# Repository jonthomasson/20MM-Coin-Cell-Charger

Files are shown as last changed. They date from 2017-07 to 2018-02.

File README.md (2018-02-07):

# 20MM-Coin-Cell-Charger
USB based coin cell charger for 2016, 2020, 2025, 2032

This is a very small and affordable lithium coin cell charger. It'll charge several 20mm type coin cell batteries. Total BOM for me was $2 for one. I picked up 3 boards from oshpark for $7.70. The PCB is available to order from the oshpark links below. All files, including BOM to reproduce this project have been included and linked to in my github repository. 

I had the need for an LIR2032 coin cell charger to power a few projects. Unfortunately (or fortunately depending on how you look at it) , the charger I had ordered off Amazon didn't work, so I decided to build my own.

I took the guts of the Solder Sniffer 9000 project, which consisted of an MCP73831 for the charge controller, and modified it a bit to charge an LIR2032.

The main change needed was the value of R3, which is responsible for setting the max charge current. For the LIR2032, the max charge current is 35mA. By using the supplied formula in the MCP73831 datasheet (I = 1000V/R) I was able to find that a 28K resistor would give me the charge current needed. To get a decent connection to the USB socket, I tinned each of the pads a bit.

The value of R3 can be adjusted from anywhere between 28K and 67K. Of course, the higher the resistor, the less charge current and thus the longer the battery will take to charge. 

I wanted the charger to be as compact and simple as possible. For this reason I chose to create the USB plug out of the PCB to save on cost. I also shrank the total footprint of the board to just a little wider than the coin cell holder. 

![enter image description here](https://lh3.googleusercontent.com/uD5Zvyg85dlW-8f5IwnGq1qh3priR2OKTf4Tjj70FocnqzpL80pZEwNxS6ZUOIJZ3bOK8rinoLwqm-kq8-yH0MLIolsSJiKuncZRWuq5fff_9x6JYAw69AOmUJirfUg54P8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)

![enter image description here](https://lh3.googleusercontent.com/PXCVL6h58zrs98nUhsCSNDjTJsKGtNxcaz6ifn4IY02xm1BFlol4Sx9Q6Okw4b5Lm4KdBB9pGmgYVPm0FkVdIyBvV0Q52LWY7phe2oq7p3IzxVEZNmcpIT2coyVlEAW5Eqw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)

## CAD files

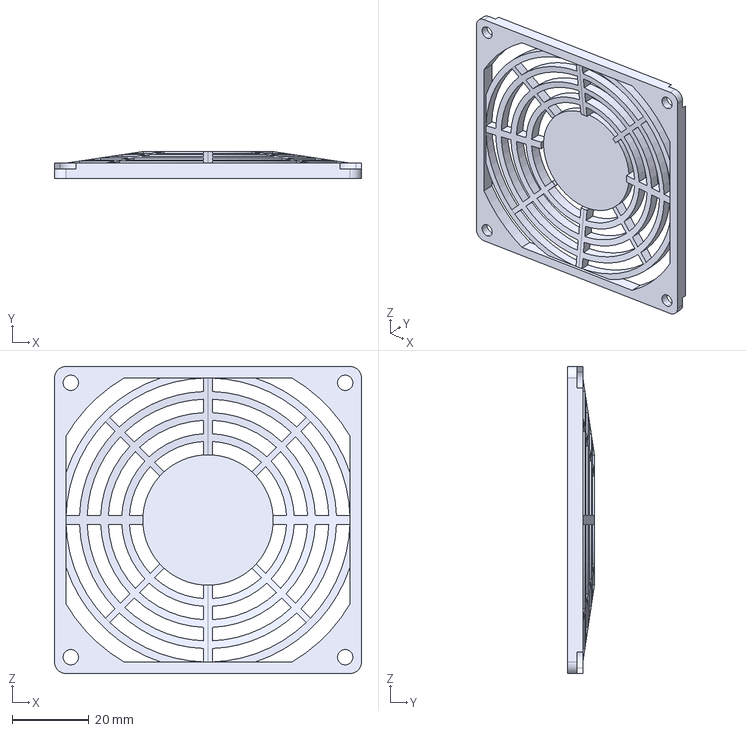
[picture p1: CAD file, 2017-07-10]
rev1.a/3dmodels/80MM_Fan_Filter.step
80.0 x 7.00 x 80.0 mm

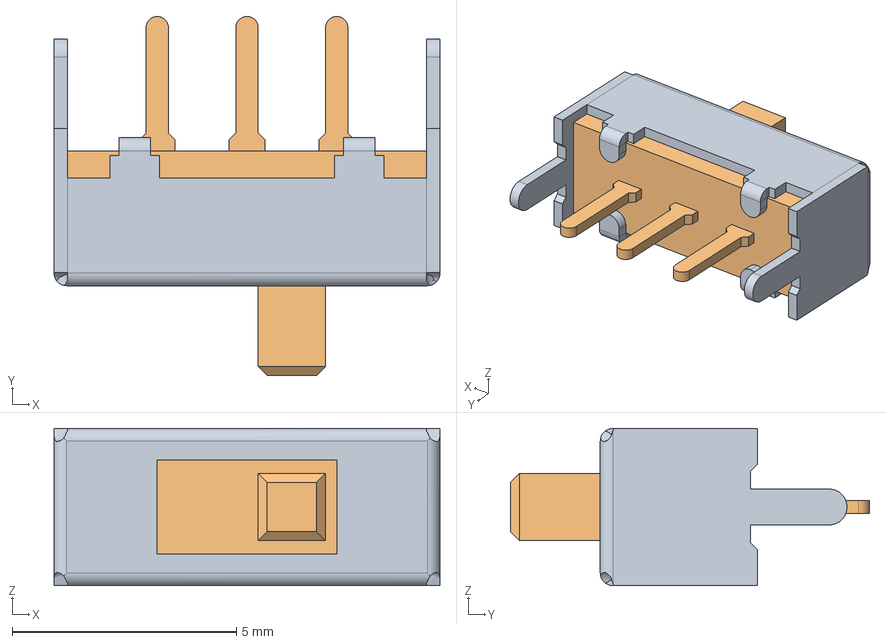
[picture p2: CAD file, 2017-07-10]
rev1.a/3dmodels/Switches_C&K_SS_12D07.step
8.60 x 8.00 x 3.50 mm

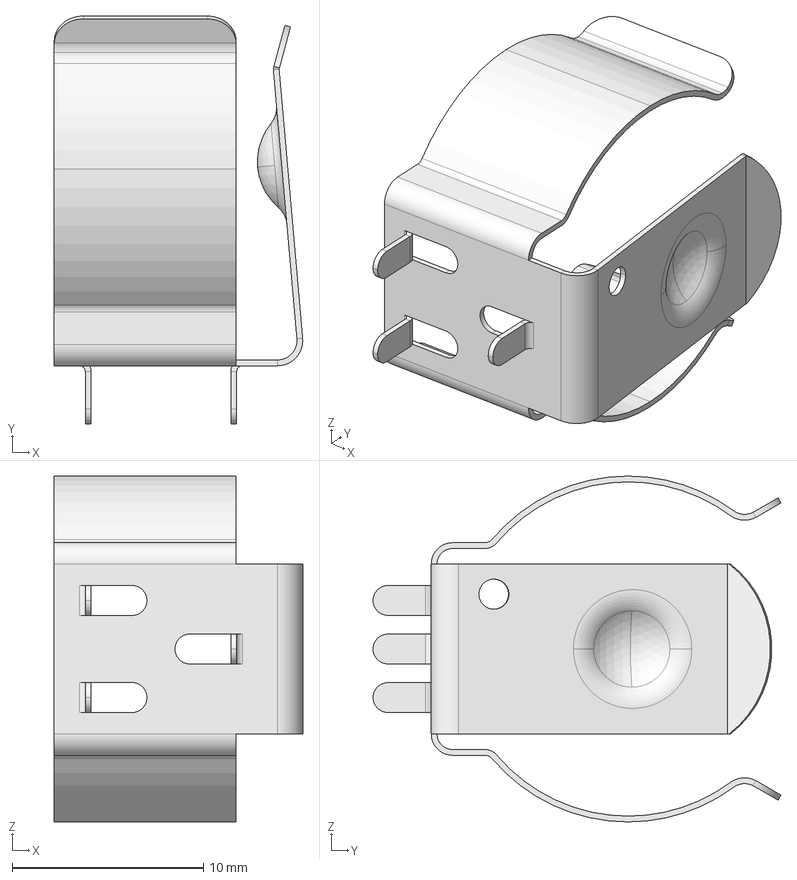
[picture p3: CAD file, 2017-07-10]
rev1.a/3dmodels/Batteries_Keystone_54.step
13.0 x 21.4 x 18.1 mm

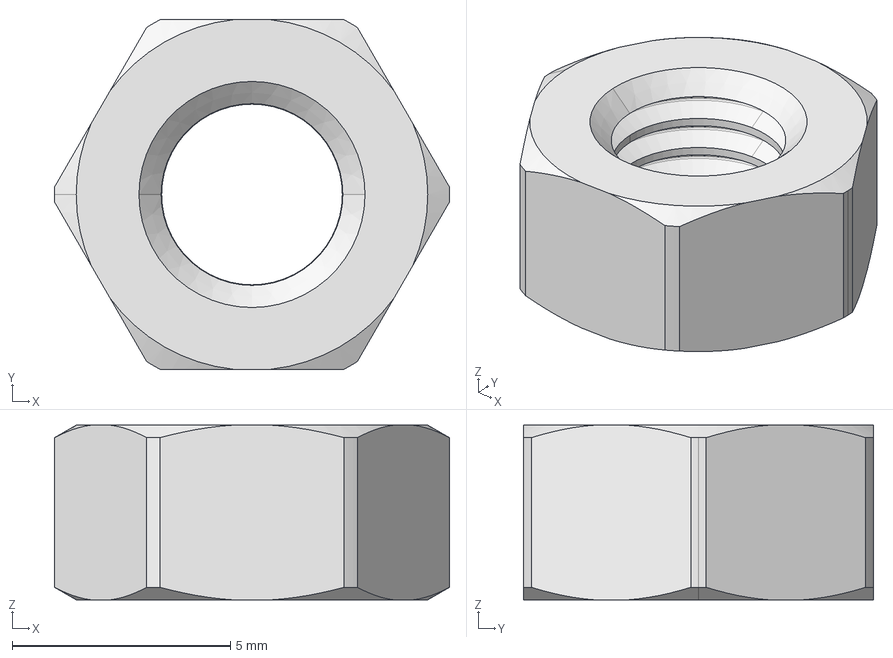
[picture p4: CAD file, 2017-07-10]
rev1.a/3dmodels/Nuts_M5.step
9.04 x 8.00 x 4.00 mm

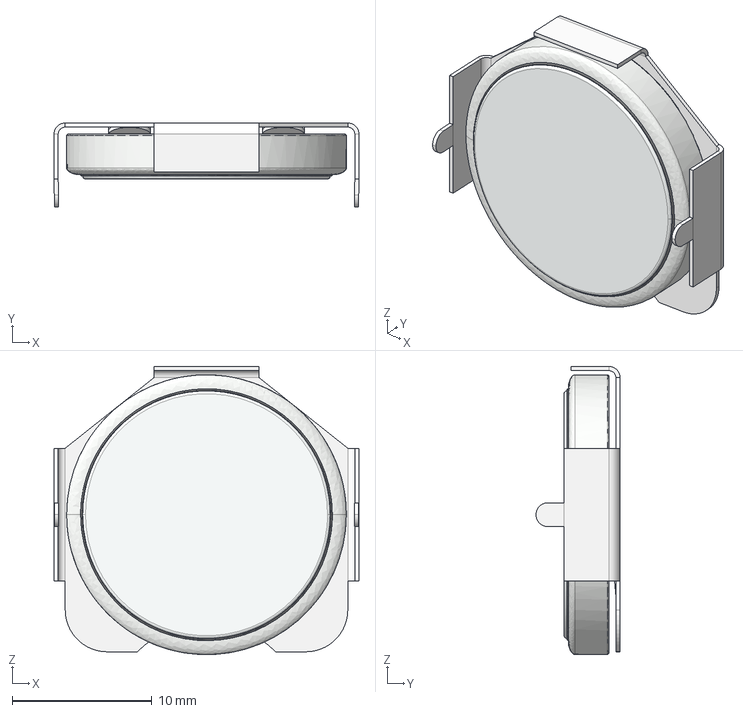
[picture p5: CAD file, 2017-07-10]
rev1.a/3dmodels/BK-888.step
21.8 x 6.01 x 20.6 mm

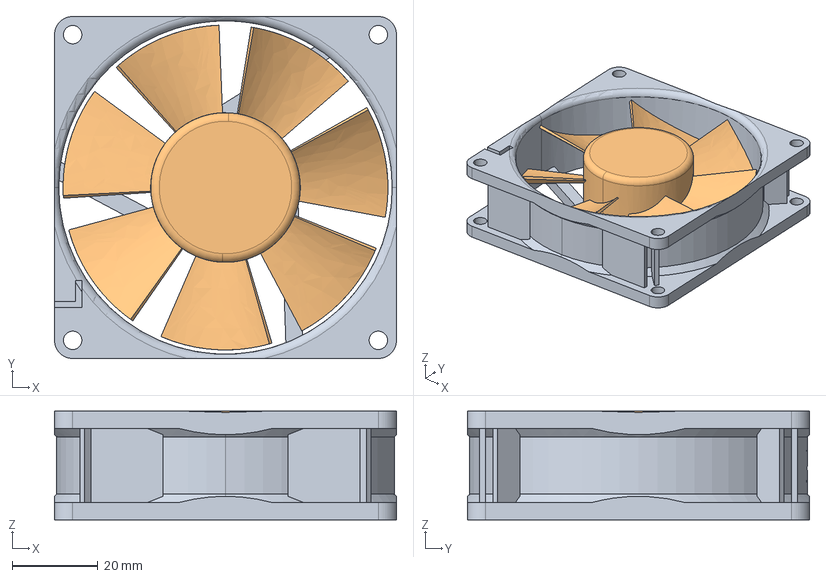
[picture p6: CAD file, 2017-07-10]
rev1.a/3dmodels/Motor_Fan.step
80.0 x 80.0 x 25.4 mm

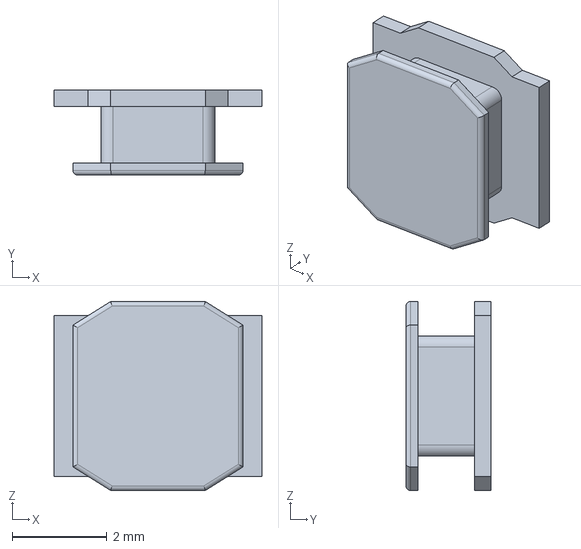
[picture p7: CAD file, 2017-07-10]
rev1.a/3dmodels/srn4018.stp
4.40 x 1.80 x 4.00 mm

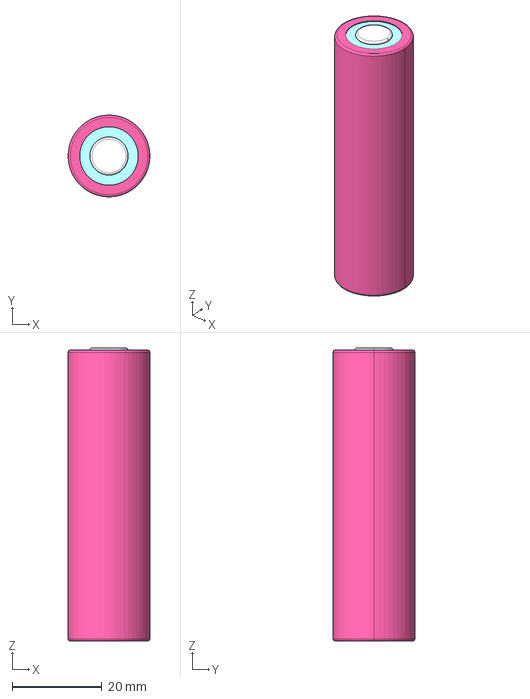
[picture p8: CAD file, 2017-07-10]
rev1.a/3dmodels/Battery_18650_c.step
18.2 x 18.2 x 65.2 mm

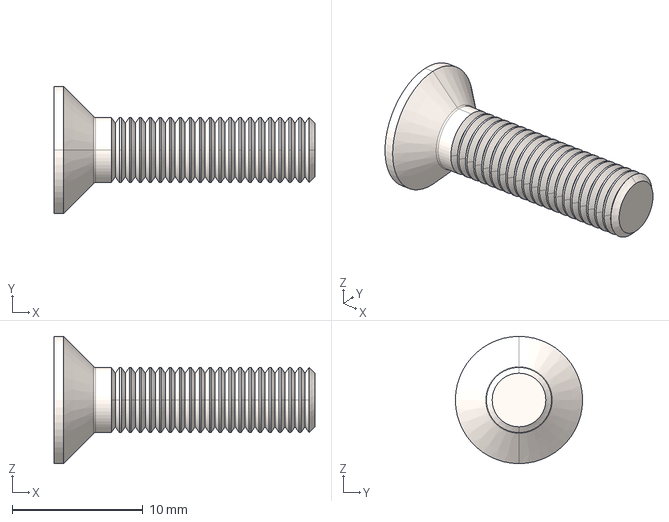
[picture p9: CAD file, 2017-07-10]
rev1.a/3dmodels/Screws_M5.step
20.0 x 9.75 x 9.75 mm

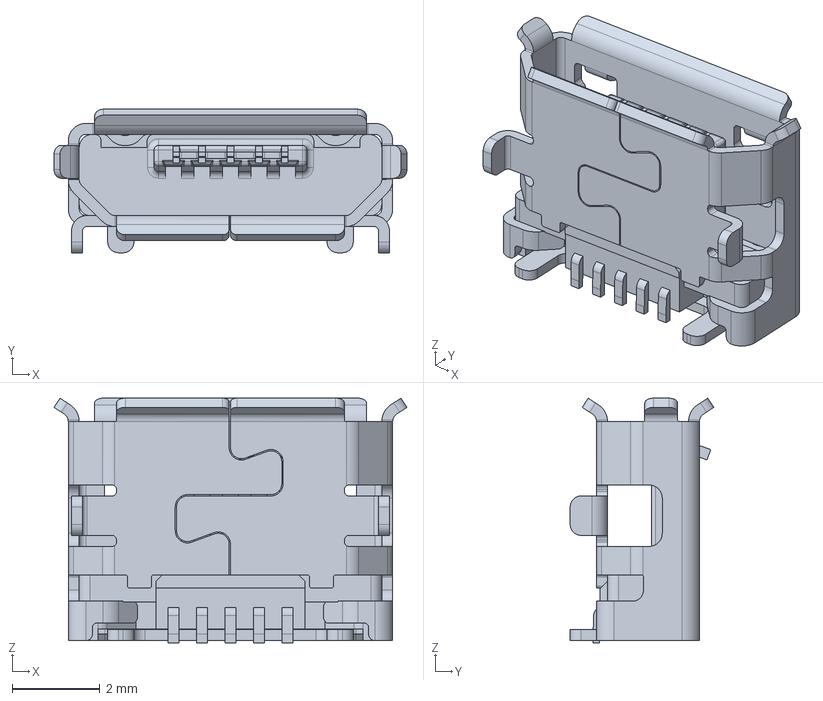
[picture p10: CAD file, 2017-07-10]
rev1.a/3dmodels/10118194c.stp
8.05 x 3.27 x 5.58 mm

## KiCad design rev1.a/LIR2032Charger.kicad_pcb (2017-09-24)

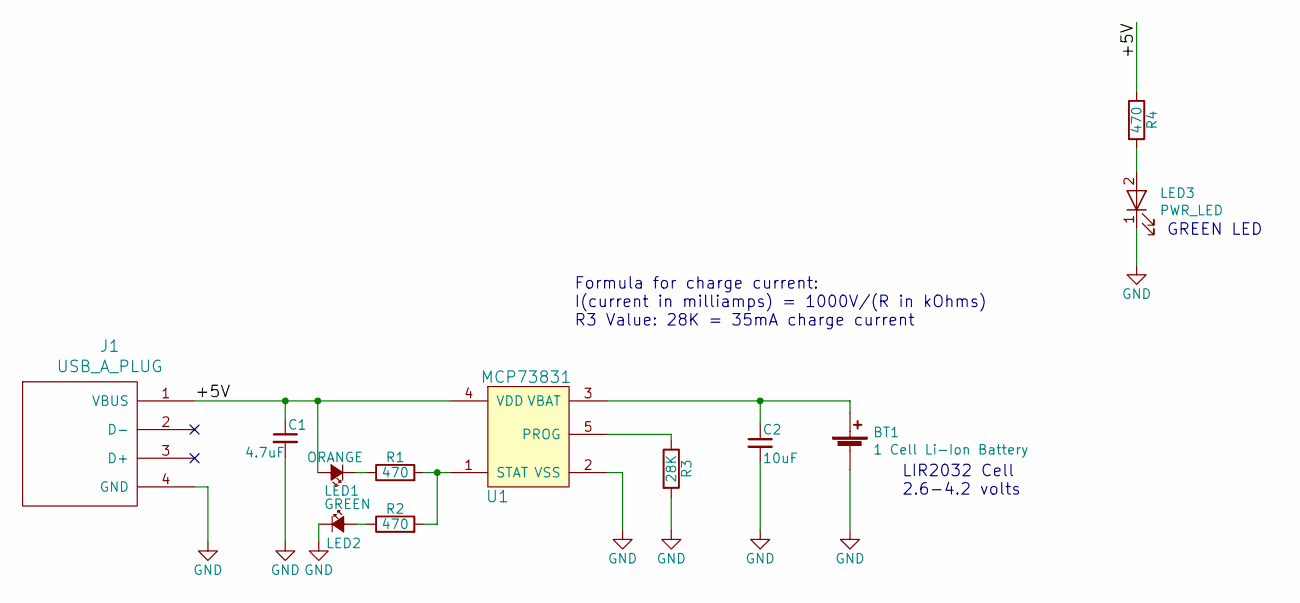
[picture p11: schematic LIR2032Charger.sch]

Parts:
BT1: 1 Cell Li-Ion Battery; BatteryHolder_MPD_BK_888
C1: 4.7uF; C_0805
C2: 10uF; C_1206
J1: USB_A_PLUG; usb-PCB
LED1: ORANGE; LED_0805
LED2: GREEN; LED_0805
LED3: PWR_LED; LED_0805
R1, R2, R4: 470; R_0805
R3: 28K; R_0805
U1: MCP73831; Microchip_MCP73831

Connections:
/+5V: C1.1, J1.1 (VBUS), LED1.2 (A), R4.1, U1.4 (VDD)
GND: BT1.2 (-), C1.2, C2.2, J1.4 (GND), LED2.1 (K), LED3.1 (K), R3.2, U1.2 (VSS)
unnamed: BT1.1 (+), C2.1, U1.3 (VBAT)
unnamed: LED1.1 (K), R1.1
unnamed: LED2.2 (A), R2.1
unnamed: LED3.2 (A), R4.2
unnamed: R1.2, R2.2, U1.1 (STAT)
unnamed: R3.1, U1.5 (PROG)

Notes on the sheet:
GREEN LED
Formula for charge current: I(current in milliamps) = 1000V/(R in kOhms) R3 Value: 28K = 35mA charge current
LIR2032 Cell 2.6-4.2 volts

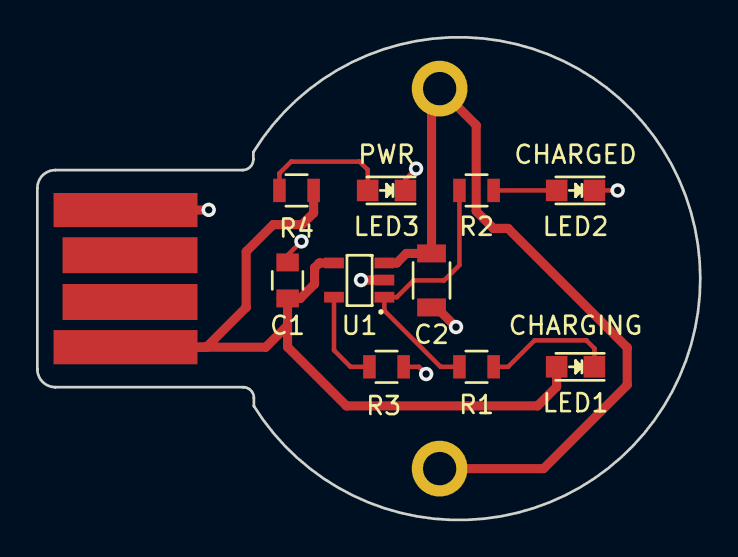
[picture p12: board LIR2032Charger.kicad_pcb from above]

Board: 2 copper layers, 36.8 x 26.8 mm, 12 parts (1 on the bottom side), 8 nets.

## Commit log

2017-07-10 initial checkin
    [10118194c.stp, 80MM_Fan_Filter.step, BK-888.step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]
2017-09-24 fixed erc errors and added gerber files
    [LIR2032Charger-B.Cu.gbl, LIR2032Charger-B.Mask.gbs, LIR2032Charger-B.SilkS.gbo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]
